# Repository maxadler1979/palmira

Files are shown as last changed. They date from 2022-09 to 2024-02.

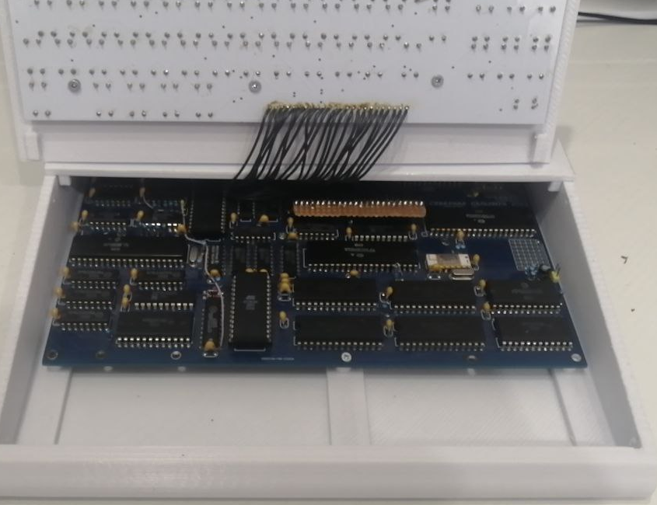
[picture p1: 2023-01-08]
пальмира_внутри.png

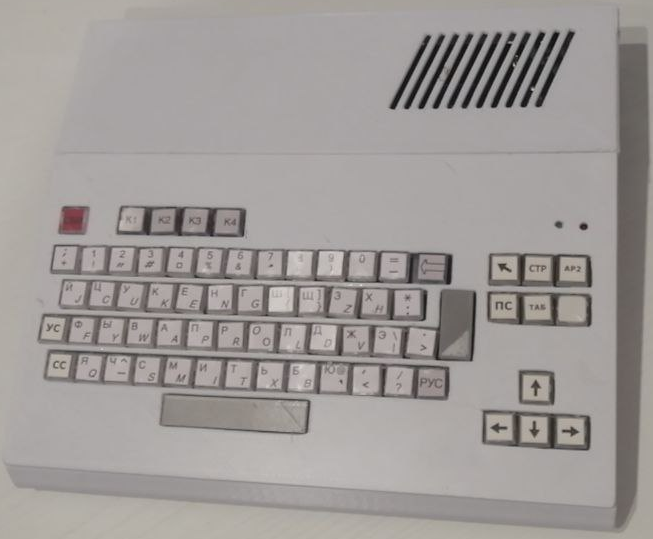
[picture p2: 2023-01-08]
пальмира.png

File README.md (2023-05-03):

# palmira
Улучшенная версия радиолюбительской ЭВМ Радио86 РК. Авторы доработок Ведущий специалист, Барсик, Виктор2313.
Центральный процессор остался КР580ВМ80А, может тактоваться частотой от стандартной 1,8 до 3х мегагерц (выборочные ревизии).
Видеочасть выполнена на БИС КР580ВГ75, имеет свой отдельный задающий генератор. Видеосигнал с цветом выводится на VGA монитор.
3х канальный звук выполнен на микросхеме таймера КР580ВИ53.
Внимание. прошивки ПЗУ устаревшие. Актуальные прошивки можно скачать из https://github.com/vpyk/palmira-stuff

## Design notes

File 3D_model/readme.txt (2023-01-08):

3D модели корпуса. Основная часть, клавиатура и верхняя крышка. Файлы открываются в Openscad.
Содержание файлов:
enter.stl - крышка для кнопки ввод
probel.stl - крышка для кнопок пробел
kb_palmira.stl - верхняя крышка для клавиатуры
verh_palm.stl - верхняя крышка корпуса
корпус_пальмира.stl - основной корпус

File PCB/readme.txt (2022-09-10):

i2c_radio - Файл печатной платы I2C расширения
radio_usb - Файл печатной платы отладчика USB
sd_radio - Файл печатной платы SD адаптера
rk86_52kRF_v2.3 - печатная плата Пальмира

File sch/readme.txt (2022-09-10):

ram_FONT_RK86 - Схема пальмиры
sd_radio - схема SD адаптера
i2c_radio - схема I2C адаптера
Схемы в формате PCAD2006

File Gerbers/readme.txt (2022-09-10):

В гербере клавиатуры допущена ошибка, поменяны местами кнопки влево и вправо. Так как исходник потерян выложено как есть.

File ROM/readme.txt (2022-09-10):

zg_rom8_ap - Файл для прошивки ПЗУ знакогенератора (со шрифтом псевдографики апогея)
mon_rom8 - Файл для прошивки ПЗУ монитора

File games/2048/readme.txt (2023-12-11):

Исходники и порт игры ДЛЯ РАДИО 86 РК.  Для компиляции запустить compile.bat, необходимо иметь на диске Z88DK.

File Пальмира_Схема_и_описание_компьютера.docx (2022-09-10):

Схема и описание компьютера.

Северная Пальмира является клоном компьютера Радио86-РК, обладает максимальной совместимостью при ряде принципиальных схемотехнических доработок. Примененные в схеме комплектующие состоят из распространенных логических микросхем и БИС комплекта серии 580 производства СССР –СНГ (кроме 2х статических ОЗУ 62256), легкодоступны и не имеют микросхем PROM или ПЛИС. Источник питания компьютера подразумевает использование внешнего преобразователя напряжений -5 и +12В. Для них предусмотрены макетные отверстия. Для подключения внешних устройств выведена системная шина и порты микросхемы кр580вв55. Разъем клавиатуры выведен стандартный и подразумевает подключение стандартной клавиатуры рк86.

Основные отличия от оригинальной версии Радио86РК:

1 – Размер шрифта 8х16 точек. Из за этого в прошивке оригинального монитора необходимо поменять настройки видеоконтроллера кр580вг75. (см. примечание 1)

2 – Поддержка атрибутов цвета и инверсии. Также в прошивке оригинального монитора необходимо поменять настройки видеоконтроллера кр580вг75. (см. примечание 1)

3 – Изменена частота видеоконтроллера, из за этого не могут поддерживаться нестандартные видеорежимы оригинала (основная проблема), например автору так и не удалось настроить режим , где количество символов в столбце может быть больше 23. Возможно данная проблема кроется в том, что размер символа вырос до 16 точек.

4 – Выход на бытовой телевизор переделан на выход VGA для подключения жк монитора. Для поддержки частот монитора соответственно пересчитаны частоты видеоконтроллера (см пункт3).

Тем не менее, появились достоинства, отличающие данный компьютер как по функционалу так и по техническим характеристикам, при сохранении полной совместимости с 90% старого ПО.

Основные нововведения:

1 – Область памяти может программно расширяться до 16 КБ по адресам 0x8000 – 0xBFFF. При этом порты переключаются на адреса памяти 0xC200 и 0xC400 соответственно.

2 – Добавлена дополнительная память 2КБ по адресам 0xD000-0xD7FF.

3 – Добавлен программно переключаемый банк памяти объемом 32КБ на стандартные адреса 0x0000-0x7FFF.

4 – Добавлен музыкальный синтезатор(трехканальный таймер), позволяющий использовать в программах 3 канальную полифонию. Адрес 0xCC00.

5 – Появились 3 дополнительных адреса выборки внешней периферии благодаря расширенному дешифратору. (адреса 0xC600,0xC800 и 0xCA00)

6 – ОЗУ в области 0xD800-0xDFFF может программно переключаться для использования вместо ПЗУ знакогенератора, благодаря чему возможно применение альтернативного шрифта с изменением в ходе выполнения программы. ОЗУ доступно как на чтение так и на запись. При применении в работе с ВГ75 ОЗУ для считывания и записи недоступно. Для изменения содержимого этого ОЗУ, достаточно переключить 1 бит в управляющем байте и записать этот байт в область памяти 0xCE00.

7 – ПЗУ знакогенератора расширена до 8 КБ, благодаря чему появилась возможность программно переключать еще 3 вида альтернативных знакогенераторов.

8 – ПЗУ монитора расширено до 8 КБ, находится в адресах 0xE000-0xFFFF.

9- Добавлен программный переключатель, находящийся по адресу 0xCE00. Благодаря нему можно переключать периферию контроллера (до 5 устройств) один бит триггера выведен на внешний порт и может использоваться альтернативно.

10 – Процессорная часть и дисплейная часть компьютера тактируется разными частотами, благодаря чему появилась возможность тактирования микропроцессора вплоть до 3 МГц. При этом тактовая частота ВИ53 остается неизменной, так как она тактируется от частоты видеоконтроллера.

11 – В видеоконтроллере использованы все атрибуты, благодаря чему появилась возможность использовать атрибуты цвета и инверсии. Цветовая схема приведена к стандартам Толкалина и Акименко.

12 – Изменен размер шрифта символа до 8х16 точек. Благодаря этому применяемая псевдографика и шрифты обрели более изящный вид. Также, благодаря применению ОЗУ в качестве знакогенератора теперь стало возможно применять в игровых программах более качественные графические спрайты (до 127 спрайтов на одном экране при цветовой палитре до 8 цветов на 1 спрайт).

Рассмотрим более подробно периферию и блоки компьютера:

Процессорная часть система его тактирования и модуль DMA остался стандартным и схемотехнически не менялся.

Порты ввода вывода и клавиатура также не изменились. Схема компаратора для магнитофона не внедрялась, так как компьютер не рассчитан на использование с магнитофоном. Отверстия портов магнитофона выведены под альтернативное подключение. Отдельно стоит отметить схемотехнику видеоконтроллера, модуля дешифратора, 3х канального таймера, переключателя знакогенератора и блока ОЗУ.

Таблица адресов распределения памяти

0000 – 7FFF | Основное ОЗУ
8000 - BFFF | Дополнительное ОЗУ
C000 – C200 | Регистры видеоконтроллера
C200 – C3FF | Порт клавиатуры
C400 – C5FF | Порт расширения
C600 – C7FF C800 – CBFF CA00 – CBFF | Резерв Резерв Резерв
CC00 – CDFF | Регистры таймера ВИ53
CE00 - CFFF | Байт расширения конфигурации
D000 – D7FF | Дополнительное ОЗУ
D800 – DFFF | ОЗУ знакогенератора
E000 | Регистры контроллера ПДП
E000 - FFFF | ПЗУ монитора

Таблица разрядов байта расширения конфигурации

7 | 6 | 4 | 3 | 2 | 1 | 0
1–ОЗУ 0000-BFFF 0–ОЗУ 0000-7FFF | Переключение ОЗУ 0xD800 – 0xDFFF в работу в видеоконтроллере 1 – ОЗУ в работе с видеоконтроллером, 0 – ОЗУ в памяти процессора | Резерв | Биты конфигурации знакогенератора (разбивает 8КБ ПЗУ на 4 разных ЗГ) | | | Переключение банков ОЗУ по 32КБ 0 – основной банк, 1 – дополнительный банк

Пример. Если записать байт 0х82 по адресу 0хCE00 то будет выбран знакогенератор графического режима апогей бк01. Вся графика этого компьютера будет доступна на этом компьютере.

Ниже на рисунке приведена распиновка системного разъема расширения.

Системный разъем содержит шину данных компьютера, свободные адреса дешифратора, сигналы чтения записи, 5 адресных линий. Также к разъему подведено питание компьютера 5В. Этого достаточно для подключения всевозможной периферии от внешних видеоадаптеров до плат расширения.

Для проверки системного разъема автор развел несколько плат расширения, это плата отладчика (по сути это USB-COM переходник, который может использоваться как ком порт компьютера) и плата I2C контроллера. Под плату USB отладчика в ПЗУ компьютера прошит отладчик, который вызывается директивой O. Со стороны ПК должно работать программа NO Ice.

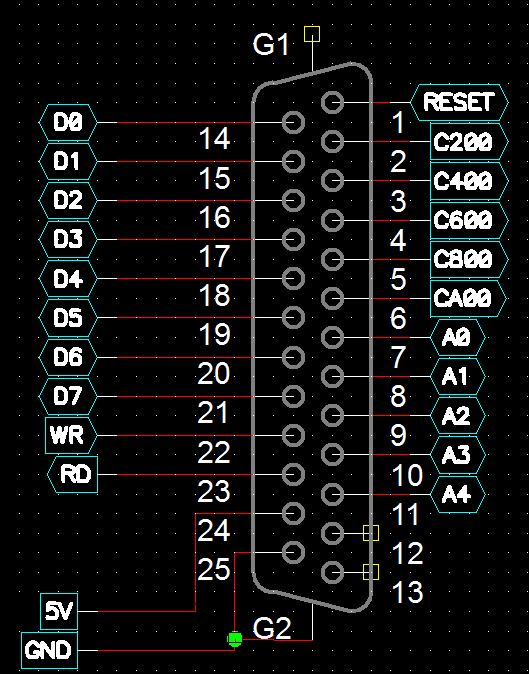
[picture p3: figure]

Дешифрирование микросхем ОЗУ по 2КБ осуществляет следующая схема.

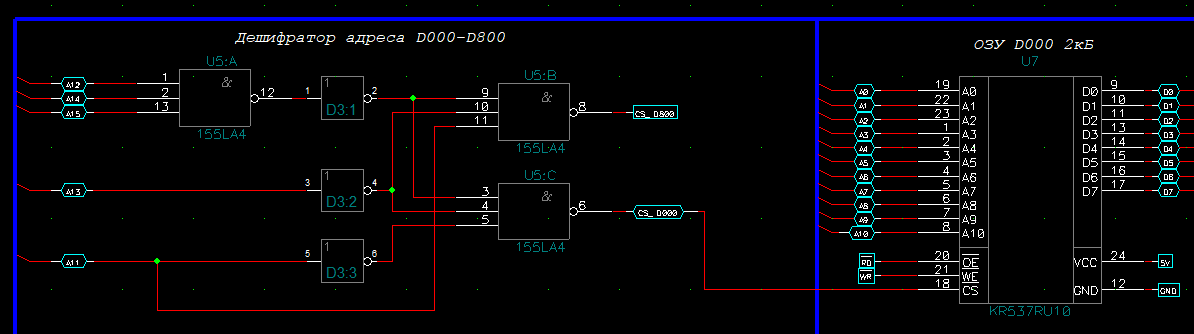
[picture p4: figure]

За переключение микросхемы ОЗУ в область памяти 0xd800-0xdfff отвечает следующие микросхемы. Для работы ОЗУ в шине процессора служит микросхема кр1533ап6, для переключения ее в работу с ВГ75 – кр1533ап5.

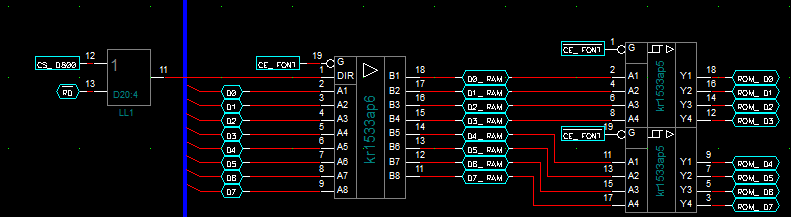
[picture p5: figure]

За переключение ОЗУ в работу с вг75 отвечают 4 микросхемы кр1533кп11.

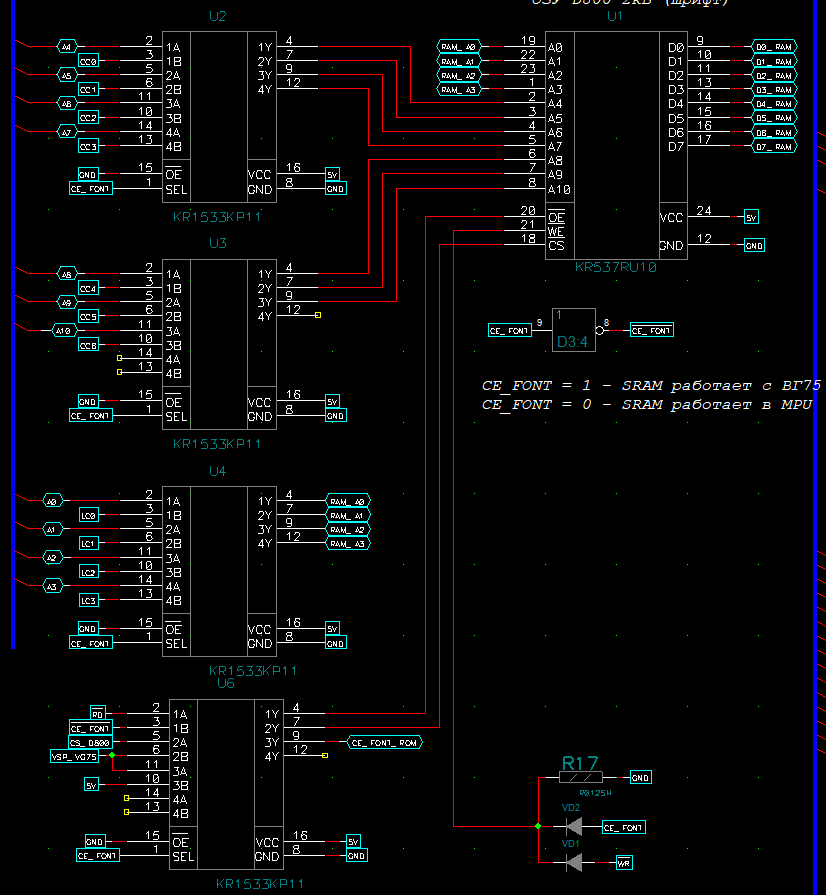
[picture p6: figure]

Программное переключение выполняет следующая схема.

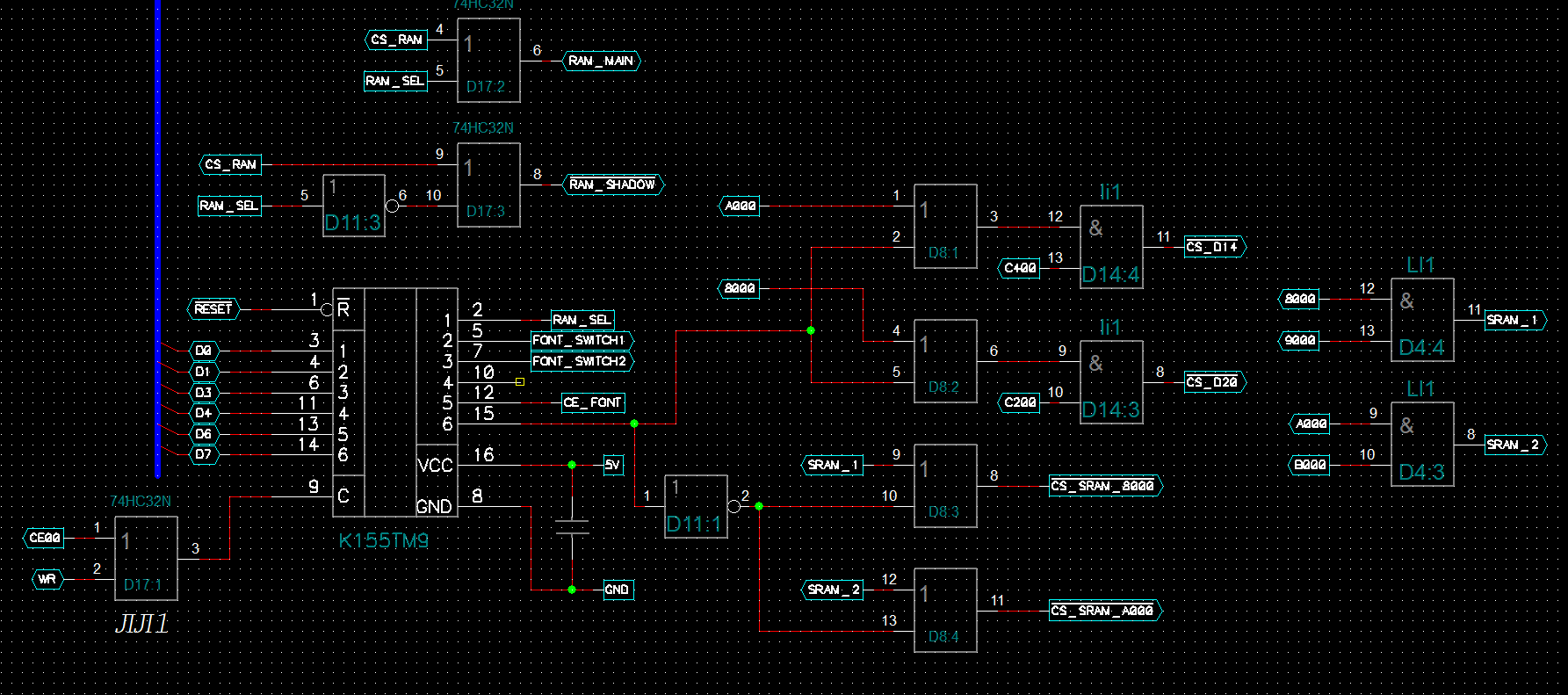
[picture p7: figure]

Для непрерывной выборки микросхем ОЗУ служат микросхемы D4.3 и D4.4. Для переноса портов В/В и клавиатуры служит логика из D8, D14, D11. При подачи из вывода 6 микросхемы к1533тм9 логического состояния, происходит переключение адресов выборки на ОЗУ вместо портов и наоборот.

Микросхемы ОЗУ по 8 КБ каждая имеют стандартное включение.

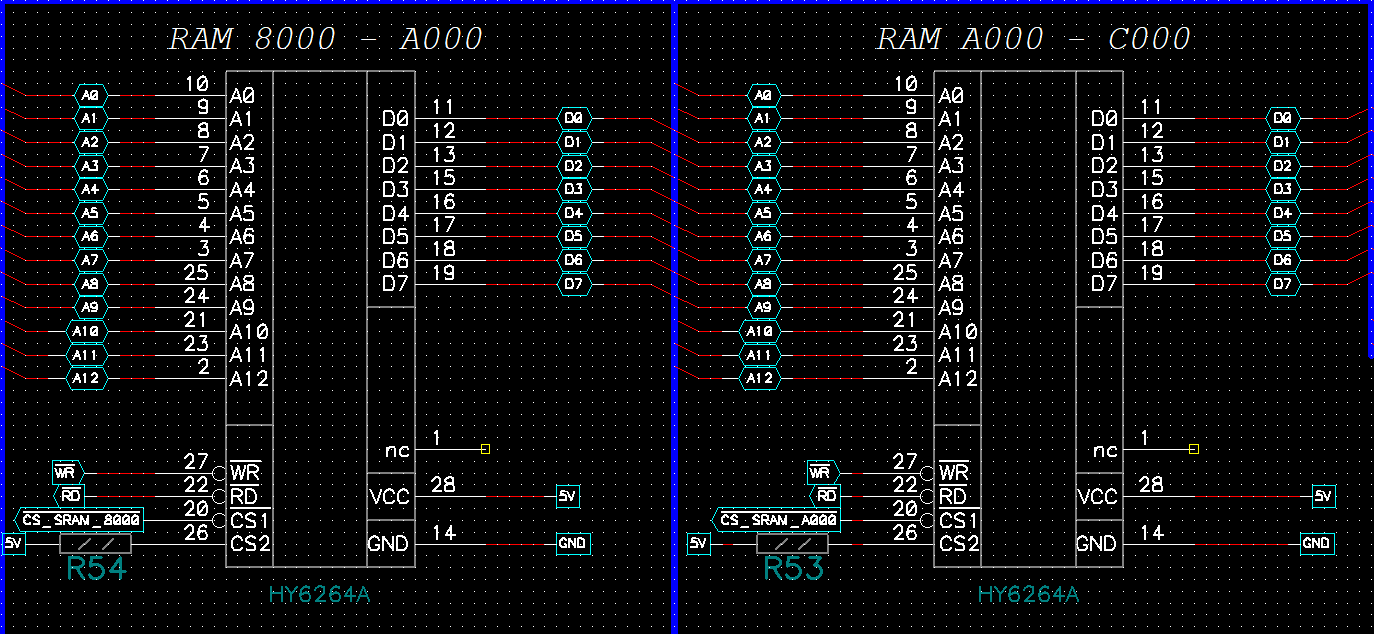
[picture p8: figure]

Для переключения банков ОЗУ по 32КБ предназначены микросхемы D17.2, D17.3 И D11.3

Основная и дополнительная RAM имеют стандартное включение

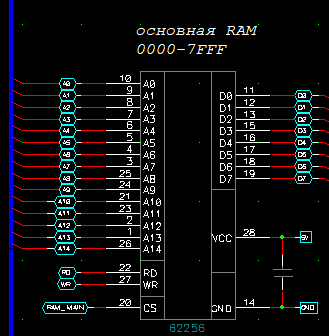
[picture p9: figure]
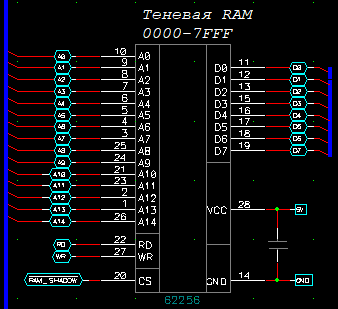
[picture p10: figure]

В качестве звуковой микросхемы используется 3х канальный таймер кр580ви53. Выходы микросхемы запараллелены резисторами номиналом 1кОм и через конденсатор выведен на контакт для подключения внешнего усилителя. Для усилителя на плате предусмотрены макетные отверстия.

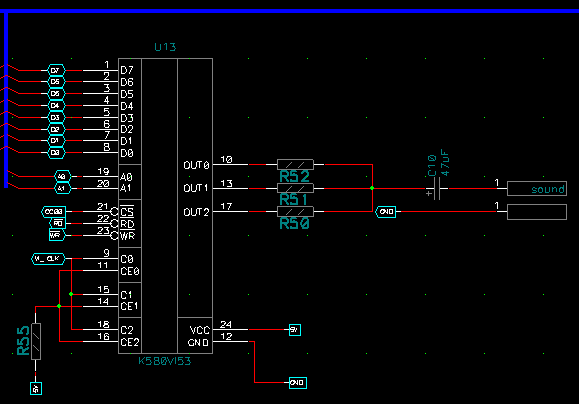
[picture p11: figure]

Для тактирования таймера используется микросхема кр1533ие5, тактовая частота для нее берется от генератора видеокарты

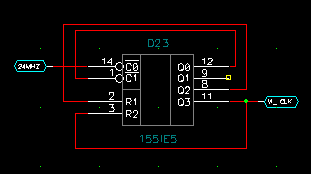
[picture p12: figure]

Дешифратор компьютера выполнен по стандартной схеме и состоит из 2 микросхем кр1533ид7. Схема сброса стандартная и не нуждается в пояснениях. Несколько слов о выборке ПЗУ монитора. Благодаря вентилям микросхемы D14 выборка осуществляется с адреса 0xE000. Выборка видеоконтроллера кр580вг75 висит на «родном» адресе 0xC000. DMA контроллер также подключен по стандартным в РК адресам 0xE000.

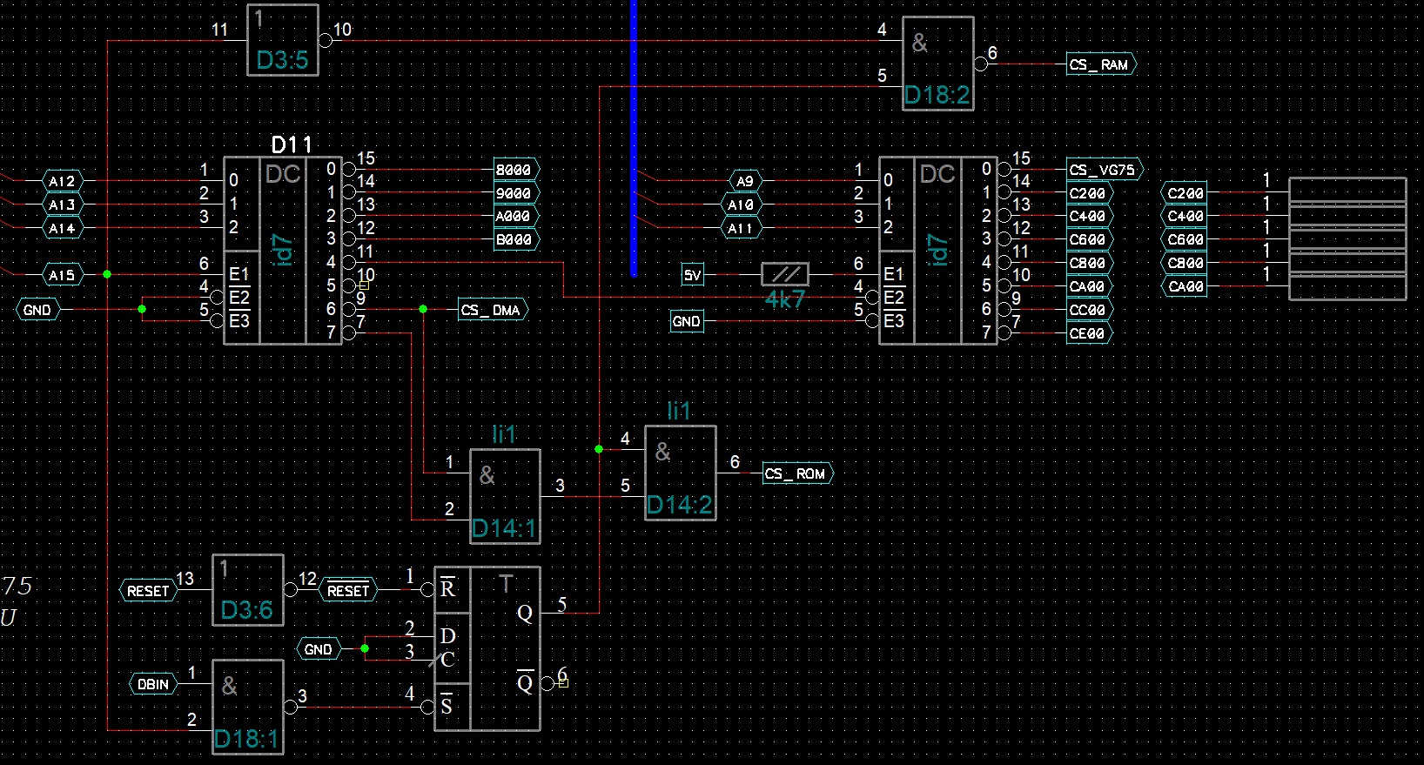
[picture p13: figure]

Процессор , его тактирование и контроллер DMA выполнен по стандартной схеме

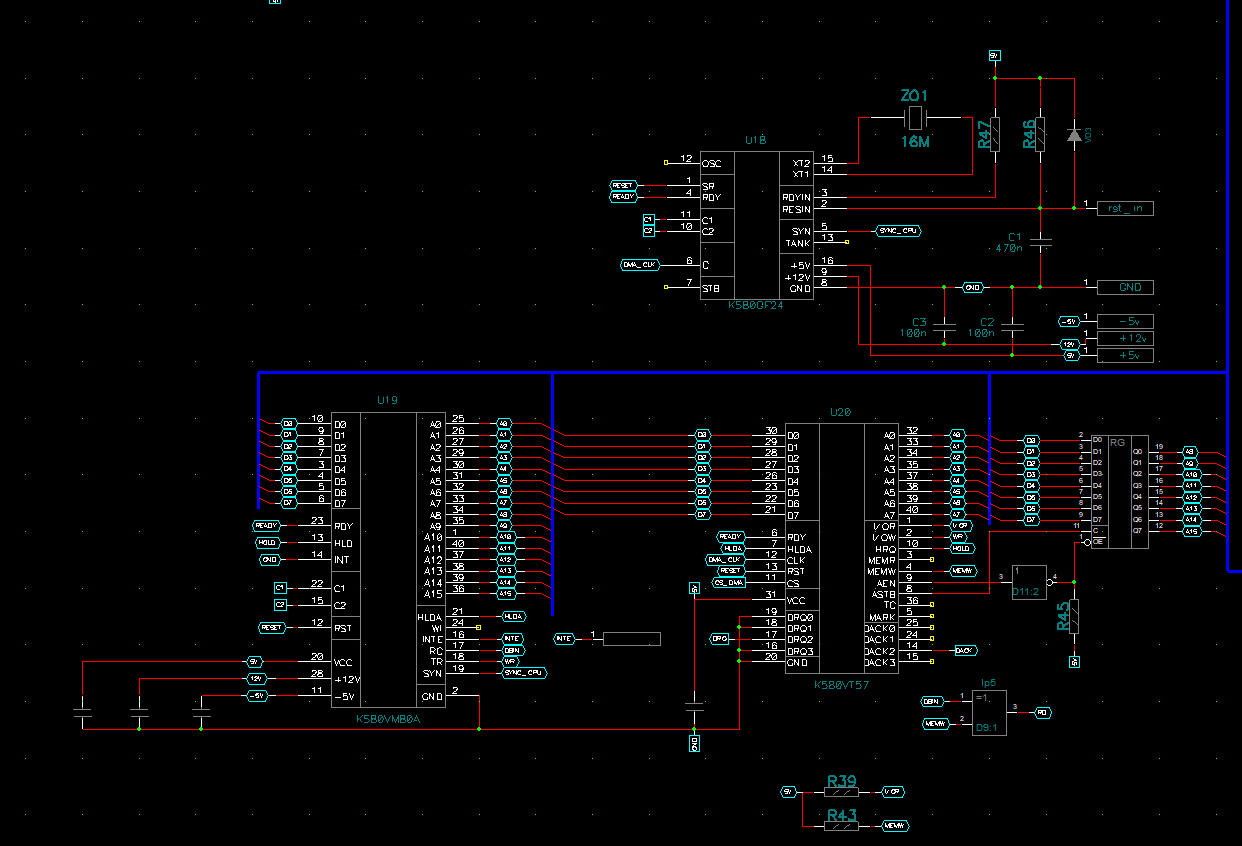
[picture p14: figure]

Порты ввода вывода и клавиатуры также выполнены по стандартной схеме РК

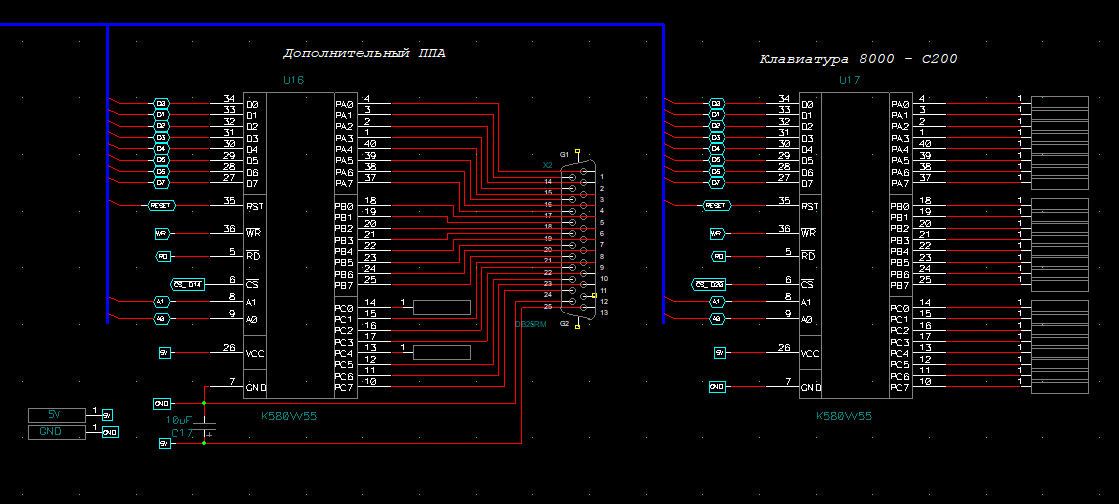
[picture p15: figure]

Разъем порта ВВ разведен на разъем DB25 который позволяет подключить периферию непосредственно к плате.

Для загрузки ПО в компьютер предусмотрен внешний дисковый контроллер, выполненный по схеме и проекту Алексея Морозова. По вызову директивой I монитора происходит считывание BIOS в память компьютера и далее загружается файловая оболочка. Пользователю остается только выбрать файл для загрузки. Проект и файлы можно найти в репозитории.

Схема видеоконтроллера:

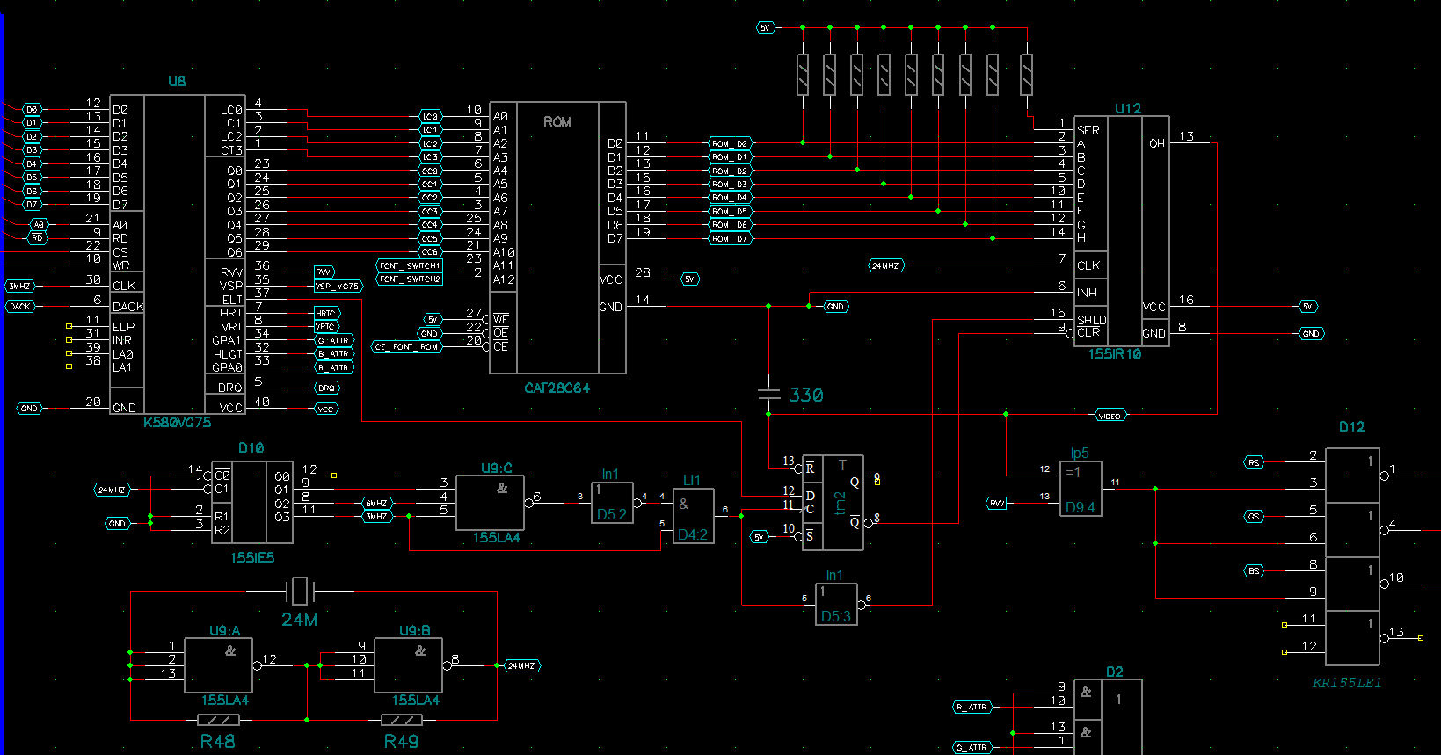
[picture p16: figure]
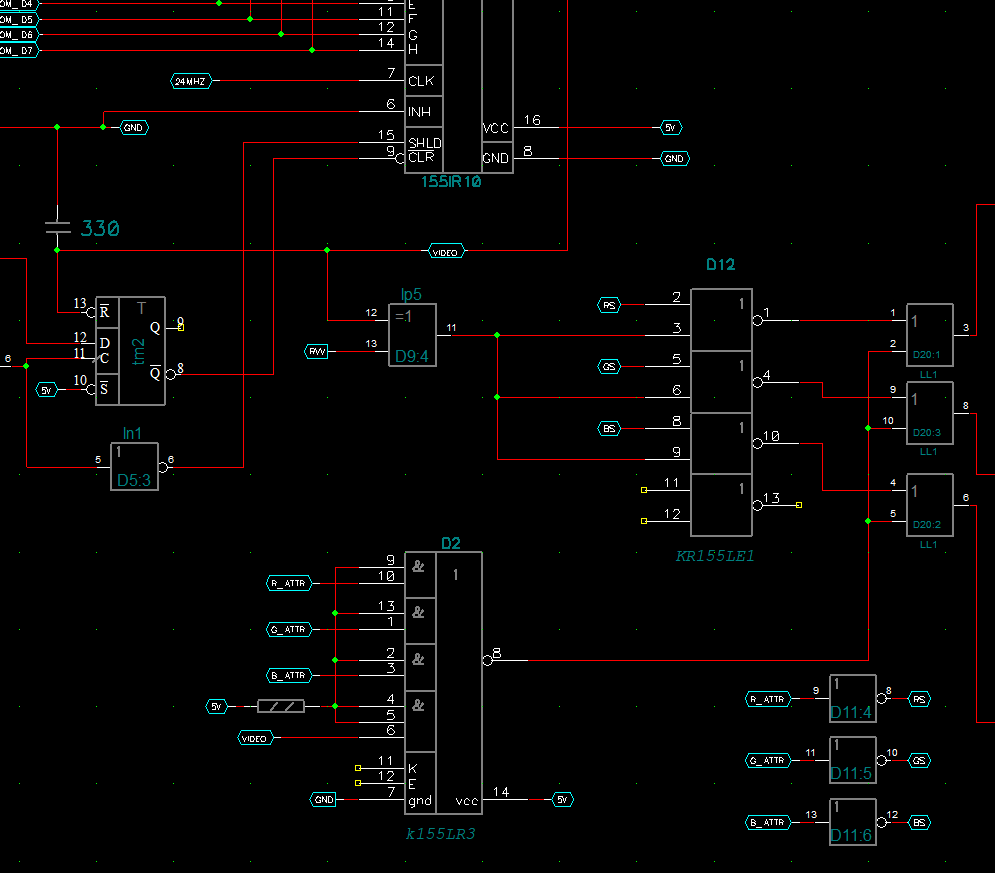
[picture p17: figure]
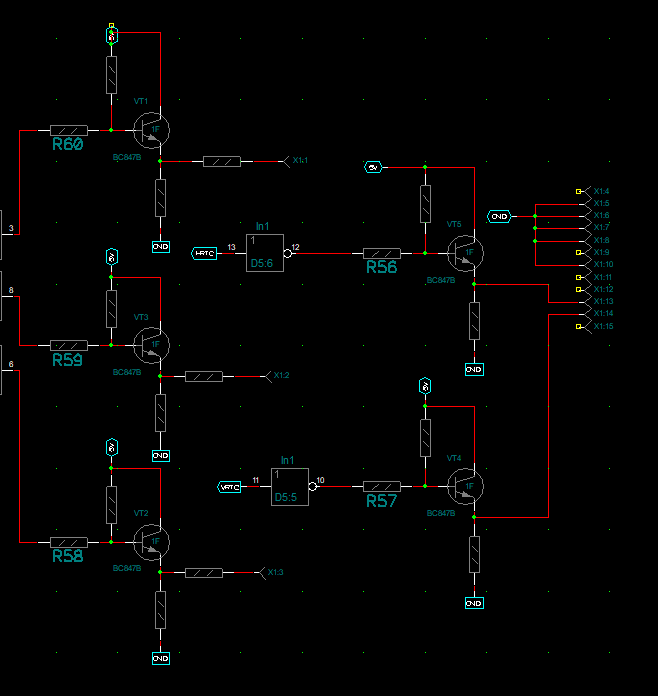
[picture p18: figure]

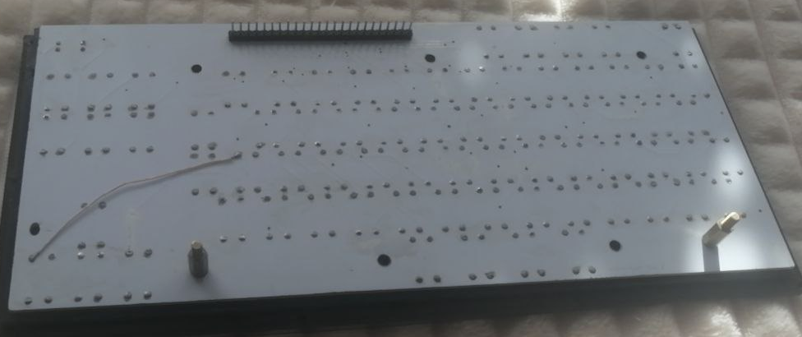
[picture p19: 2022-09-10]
foto/kb_bot.png

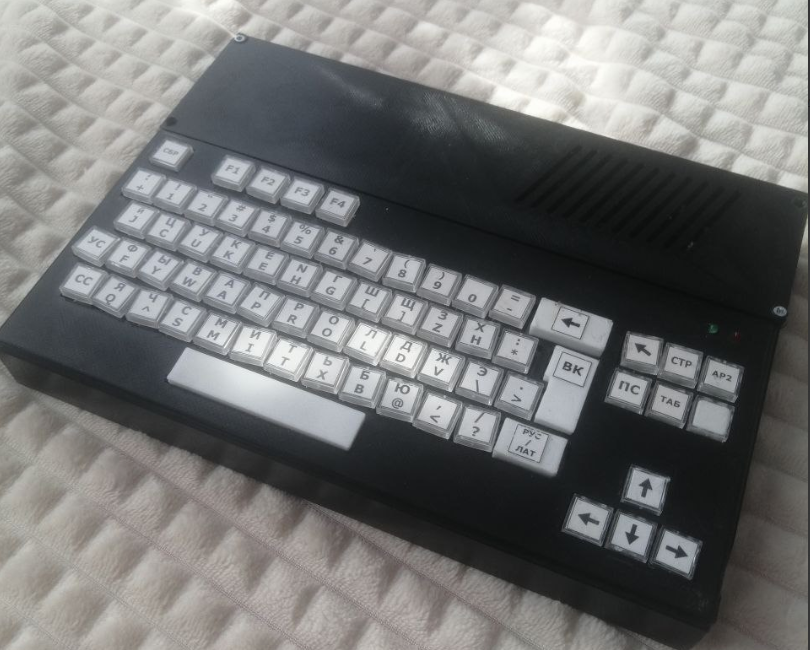
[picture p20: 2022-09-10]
foto/palm.png

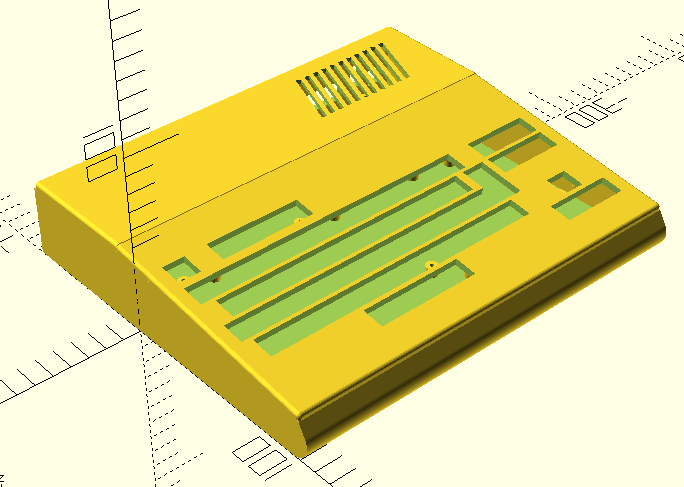
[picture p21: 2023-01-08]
3D_model/корпус.png

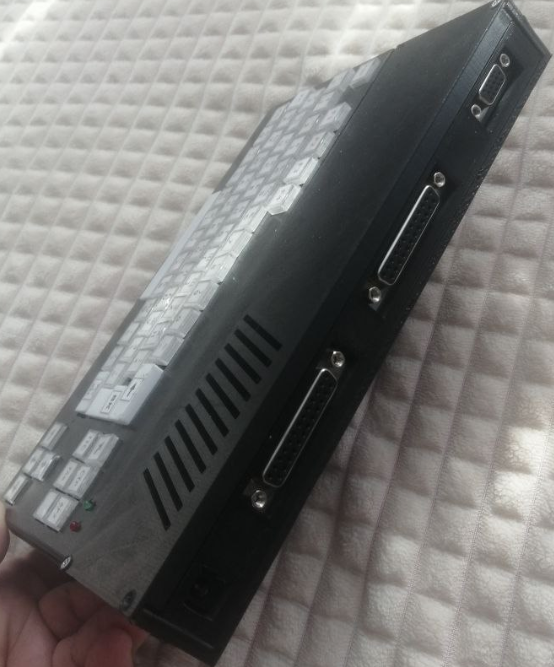
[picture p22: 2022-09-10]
foto/palm2.png

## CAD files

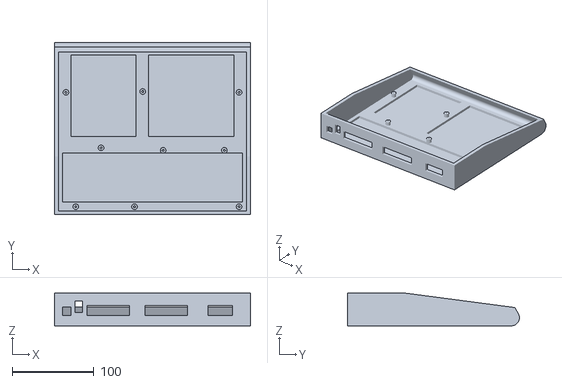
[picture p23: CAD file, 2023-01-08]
3D_model/корпус_пальмира.stl
240.0 x 210.5 x 40.0

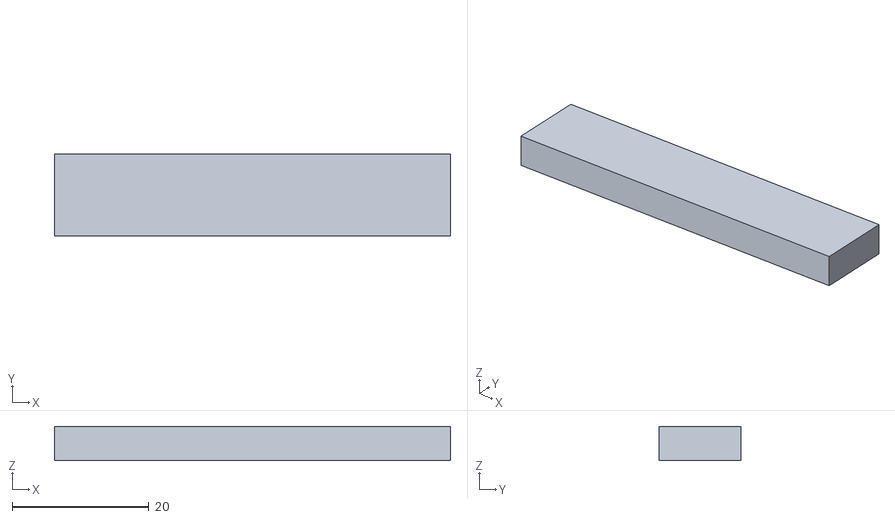
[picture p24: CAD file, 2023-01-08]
3D_model/probel.stl
58.0 x 12.0 x 5.00

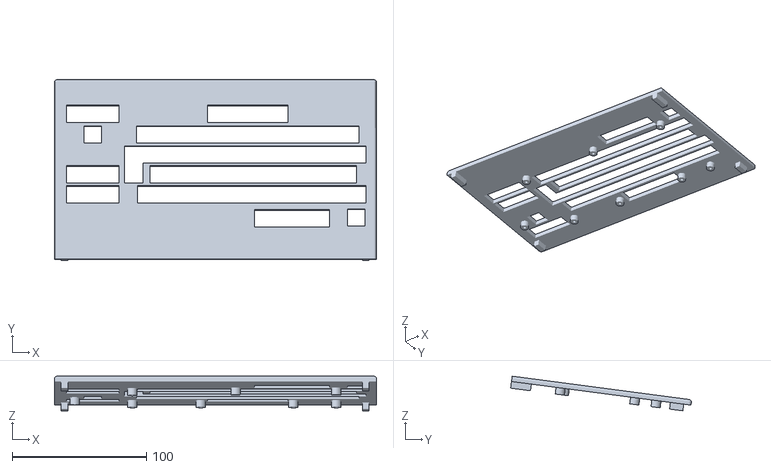
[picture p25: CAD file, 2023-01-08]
3D_model/kb_palmira.stl
240.0 x 134.8 x 25.8

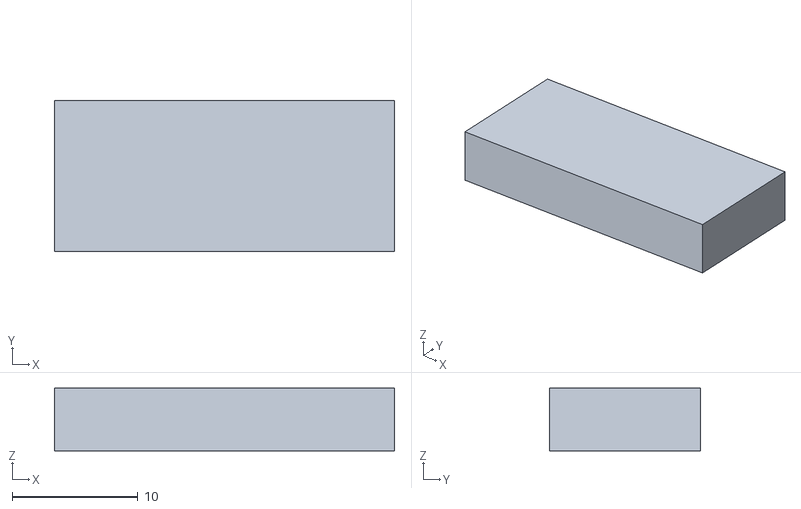
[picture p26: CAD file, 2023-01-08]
3D_model/enter.stl
27.0 x 12.0 x 5.00

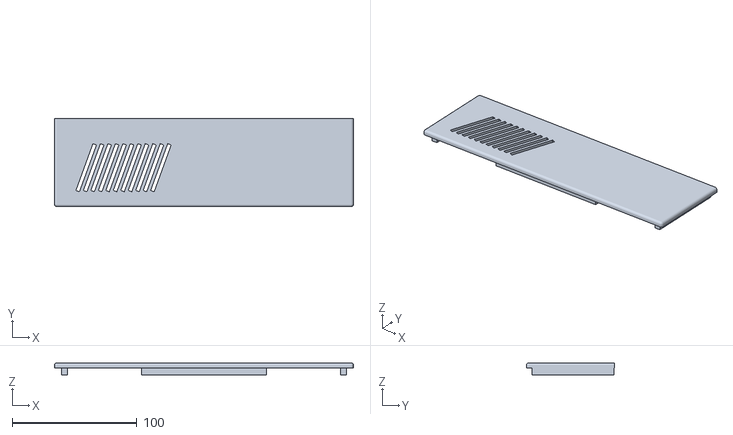
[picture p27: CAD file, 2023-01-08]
3D_model/verh_palm.stl
240.0 x 71.0 x 9.99

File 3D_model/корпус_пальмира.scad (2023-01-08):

module prizm_add_dfask(n, height, rib, r_fask, fn_fask, center = false)
{
  r = rib/sqrt(3);
  minkowski()
  {
    cylinder(height/2, r, r, $fn=n, center);
    cylinder(height/2, r_fask, r_fask, $fn=fn_fask*32, center);
  }
}

//базовая призма
module prizm_side(n, w, h, r, center = true)
{
  rotate([0,-90,180])
  {
    prizm_add_dfask(n, w, h, r,16, center);
  }
}
//призма - труба
module prizm_box(n, w, h, r, t, center = true)
{
  r2 = (r-t < 0) ? 0.1 :  r-t;
  rotate([0,-90,180]) difference()
  {
    prizm_add_dfask(n, w, h, r,16, center);
    translate([0,0,-0.5])prizm_add_dfask(n, w+3, h, r2,16, center);
  }
}








h=230;
r=10;
t= 5; // толщина корпуса
w=127;
z = h/(sqrt(3)*2) + r;
h2=40;
ts = 8; // толщина боковой стенки
ts2 = 5;


module stylus(h, r, fn_fask)
{
  difference()
  {
      union()
      {
        translate([0,0,h-r]) sphere(r,$fn=fn_fask*1);
        cylinder(h-r,r,r,$fn=fn_fask);
      }
      translate([-r,0,0]) cube([2*r, r, h]);
  }
}

module half_box_fask(w,l,h,r_fask,fn_fask)
{
  fn = fn_fask*4;
  translate([w/2,l/2,0]) hull()
  {
    translate([-w/2+r_fask,-l/2+r_fask,0]) stylus(h, r_fask, fn);
    translate([-w/2+r_fask,l/2,0]) stylus(h, r_fask, fn);
    translate([w/2-r_fask,-l/2+r_fask,0]) stylus(h, r_fask, fn);
    translate([w/2-r_fask,l/2,0]) stylus(h, r_fask, fn);
  }
}

module case_rk_top()
{
    difference() {
          
     half_box_fask(240,71,4,2,10);//cube([236,61,2],false);
     translate([10,10,-0.5])cube([96,55,2],false);
     translate([116,10,-0.5])cube([110,55,2],false);
     for (i=[140:6:200])
     translate([i-120,12,-0.5])rotate([00,00,70])cube([40,3,8],false);
    }


    translate([5.5,4.5,-6])   cube([5,66,6],false);
    translate([229.5,4.5,-6]) cube([5,66,6],false);
    translate([70,4.5,-6]) cube([100,4.5,6],false);
    //translate([10,0,-5]) cube([216,5,5],false);
    //translate([106,5,-5]) cube([10,45,5],false);
}

module stoyka_klav(x,y)
{
    translate([x,y,-5])
 difference() {
 cylinder($fn = 30, h = 6, r1 = 3.5, r2 = 3.5, center = false);
 cylinder($fn = 30, h = 6.5, r1 = 1.2, r2 = 1.2, center = false);   
    
}
}

module keyboard()
{
    difference() {
          
     half_box_fask(240,135,4,2,9);// cube([240,110,7],false);
     translate([2,20,0])
        {
             translate([172,41,-1.5]) cube([14,10,8],false); //пробел
        translate([64,-0.5,-1.5]) cube([60,13,8],false); //пробел
        translate([190,-0.5,-1.5]) cube([39,13,8],false);//стрелки влево вниз вправо
        translate([11,15,-1.5]) cube([166,13,8],false);  // нижний ряд
        translate([203,15,-1.5]) cube([13,13,8],false); //кнопка вверх
        translate([6,30,-1.5]) cube([180,13,8],false); //второй ряд снизу
        translate([13,45,-1.5])cube([154,13,8],false); // третий ряд снизу
        translate([172,45,-1.5])cube([14,13,8],false); //вк
        translate([190,45,-1.5])cube([39,13,8],false); //пс таб
        translate([6,60,-1.5])cube([170,13,8],false); // 4 ряд
        translate([190,60,-1.5])cube([39,13,8],false);
        translate([6.5,77.5,-1.5])cube([13,13,8],false); // сброс
        translate([33,78,-1.5])cube([56,13,8],false);
            
             
            
        }
            

    }
             stoyka_klav(30,26);
             stoyka_klav(62,26);
             stoyka_klav(131,26);
             stoyka_klav(182,26);
            
             stoyka_klav(30,98);
             stoyka_klav(105,98);
             stoyka_klav(182,95);
             stoyka_klav(225,42);
     translate([10.5,5.5,-5])rotate([0,0,90])cube([10,5,5],false);
     translate([10.5,120,-5])rotate([0,0,90])cube([15,5,5],false);
     translate([235,5.5,-5])rotate([0,0,90])cube([10,5,5],false);
     translate([235,120,-5])rotate([0,0,90])cube([15,5,5],false);
}





module stoyka(x,y)
{
    translate([x,y,-73])
 difference() {
 cylinder($fn = 30, h = 7, r1 = 3.5, r2 = 3.5, center = false);
 cylinder($fn = 30, h = 7.5, r1 = 1.2, r2 = 1.2, center = false);   
    
}
}



zw=240;
 module main_case()
intersection()
{
  //translate([0,50,h2/2])cube([169,h,h2],true); // уберем треугольник оставим санки # - подсветка  
      translate([0,0,h2/2])
  {
    hull()
    {  
      translate([0,-h/2+65,0]) cube([zw,71,h2],true); // уберем треугольник оставим санки # - подсветка   
     translate([0,h/2+20,-10])cube([zw,5,h2-20],true); //     
    }
  }
  translate([-00,0,z]) //rotate([0,0,0]) 
  union()
  {  
      difference() { 
       prizm_box(3, 240, h, r, t);
      
         
      /*    translate([-74,130,-65]) cube([159,6,5],false);   // фаска под клаву спереди 
       translate([-68,-87,-87.5]) cube([140,110,6],false); //дыра внизу 1
       translate([-68,37,-87.5])  cube([140,100,6],false);  //дыра внизу 2
       translate([-70,-87,-87.5]) cube([142,114,2.5],false); //фаска под дырку 1
       translate([-70,34,-87.5])  cube([142,104,2.5],false); //фаска под дырку 2
       //translate([-70,-80,-87.5]) cube([142,4,2.5],false); // фаска 
        translate([70,-83,-87.5]) cube([5,110,2.5],false); //фаска под дырку 1
          translate([70,34,-87.5]) cube([5,104,2.5],false); //фаска под дырку 1**/
      }
      difference() {
      translate([-120,0,0])prizm_side(3, ts2, h, r, 20); // боковая стенка
           // боковая стенка
     // translate([-64,-100,-52]) rotate([0,0,90]) cube([237,4,5],false);
     // translate([-63,-92,-87.5]) rotate([0,0,90])  cube([230,4,2.5],false);
     // translate([-64,18,-51.5])   rotate([0,6.8,90])  cube([126.7,4,5],false);//фаска на клаву на боковой стенке  
      }
      translate([115,0,0])prizm_side(3, ts2, h, r, 20); 
      
      // #stoyka(-94,-84);
      stoyka(-94,-76);
      stoyka(-22,-76);
      stoyka(106,-76);
      stoyka(-106,64);// -115х-81 правый левый угол -110х-81 правый верхний край платы
      stoyka(106,64);
      stoyka(-63,-4);
       stoyka(-12,65);
       stoyka(88,-7);
      stoyka(13,-7);
      difference() {
       translate([-120,-86,-86]) cube([240,5,50],false);// задняя стенка
       //-115 начало правой стенки
       translate([-100,-80,-53.5]) rotate([90,180,0])cube([10,10,6],false);// отверстие под питание
       translate([-28,-80,-51.5]) rotate([90,180,0])cube([52,12,6],false);// порт сдшки
       translate([43,-80,-51.5]) rotate([90,180,0])cube([52,12,6],false);// порт системный   
       translate([98,-80,-51.5]) rotate([90,180,0])cube([30,12,6],false);// порт системный  
       translate([-95,-80,-60]) rotate([90,0,0])cube([9,14,6.5],false);// выключатель 
      // translate([-70,-83,-52]) rotate([0,0,0]) cube([155,6,5],false); // фаска под крышку
      // translate([-70,-83,-87.5]) rotate([0,0,0]) cube([145,4,2.5],false); // фаска под крышку снизу
      // translate([-10,-78,-71]) rotate([90,0,00]) cube([56,12,6.5],false);
  //translate([-15,-85,-66]) rotate([90,0,00])#cylinder($fn = 0, h = 15, r1 = 1, r2 = 1, center = false);
  //translate([48,-85,-66]) rotate([90,0,00])#cylinder($fn = 0, h = 15, r1 = 1, r2 = 1, center = false);
       //
       //translate([-45,-78.5,-66]) rotate([90,180,0]) cylinder($fn = 0, h = 7, r1 = 8, r2 = 7.8, center = false); //питание  
      // translate([169/2,-78,-63]) rotate([90,180,0]) cube([9,14,3],false);// вставка для скрепления
      }
  }
  // translate([-0.5,5,34]) cube([237,6.5,6],false);
 }
 
module probel()
{
   
 difference() {
  cube([58,12,5],false);
  translate([1,1,-0.50])cube([56,10,4],false);  
}
}
 
 module enter()
{
   
 difference() {
  cube([27,12,5],false);
  translate([1,1,-0.50])cube([25,10,4],false);  
}
}
 

  translate([-120,0,0]) main_case();
  translate([-240,-85,40])case_rk_top();
  translate([-0,119.5,22]) rotate([7.5,0,180])keyboard();





//enter();

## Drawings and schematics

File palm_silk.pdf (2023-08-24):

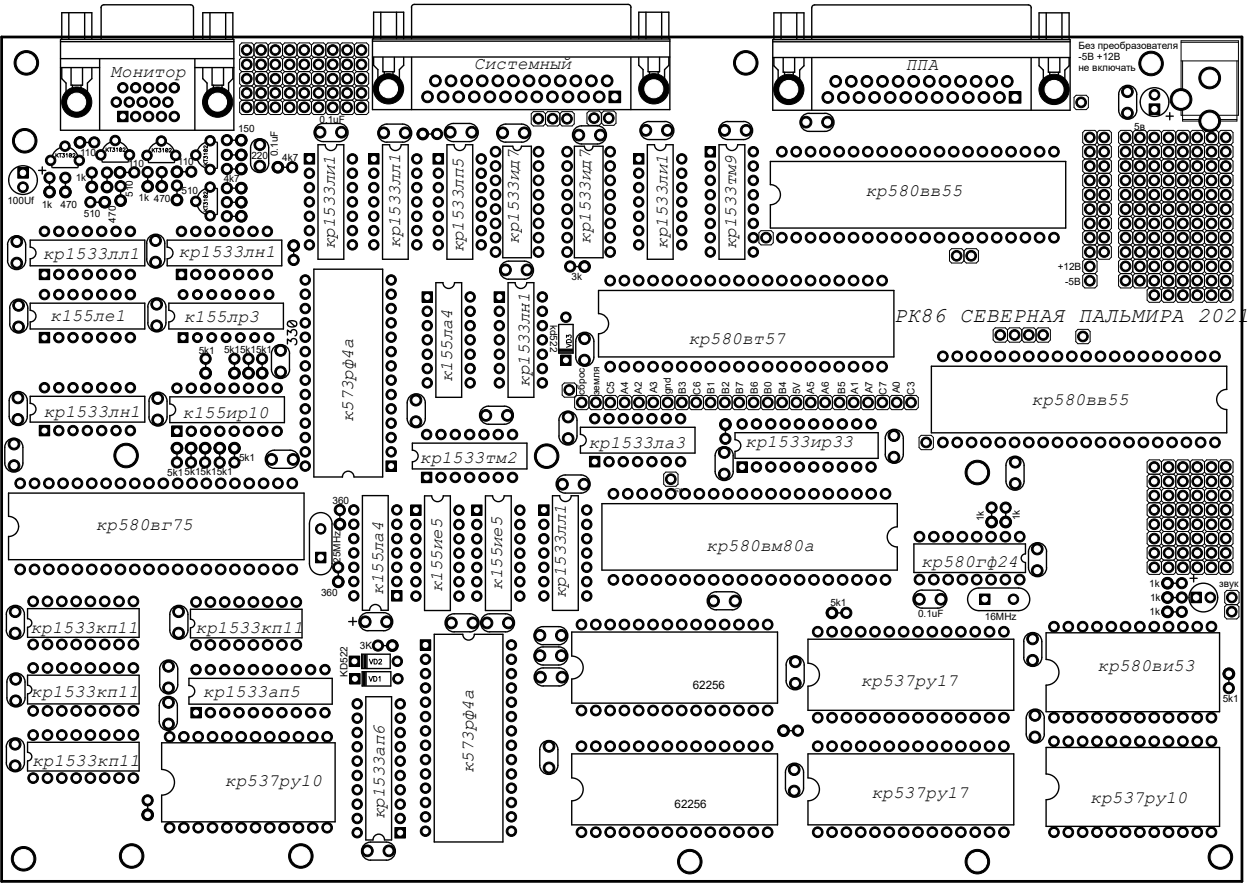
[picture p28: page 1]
Без преобразователя -5В +12В не включать; РК86 СЕВЕРНАЯ ПАЛЬМИРА 2021; земля C⁵; A²A³; B²B⁷; B⁰B⁴; A⁵A⁶; A¹A⁷; звук; 360 ²⁵MHz; 16MHz ¹k; KD⁵²²; кр580вв55 кр1533тм⁹; ППА; Монитор; Системный

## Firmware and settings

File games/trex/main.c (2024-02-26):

#include <string.h>
#include <stdint.h>
#include "main.h"
#include "splash.h"

extern void DrawString(const char* str, uint8_t x, uint8_t y);

uint8_t* VG75 = (uchar*)0xC000;
uint8_t* VT57 = (uchar*)0xE000;
uint8_t* vv55 = (uint8_t*)0xc200;
uint8_t* radio86rkVideoMem = (uchar*)(SCREEN + 78*3 + 8);
uint8_t  radio86rkVideoBpl = 78;
unsigned char coordata[2];
extern uint8_t* put_sprite_3;
extern unsigned  char dino3[];
extern unsigned  char dino2[];
extern unsigned  char dino1[];
extern unsigned char ground1[];
extern unsigned char ground2[];
extern unsigned char ground3[];
uint8_t end;
uint16_t score=0; 
extern char i_a;
extern char i_b;
extern char i_c;
extern char i_d;

unsigned char best_bmp[26] = {3,8,
	 0x13, 0x10, 0x13, 0x01, 0x12, 0x01, 0x07, 0x01,
         0x13, 0x10, 0x13, 0x01, 0x02, 0x10, 0x06, 0x00, 
	 0x03, 0x00, 0x03, 0x01, 0x03, 0x00, 0x02, 0x00
};
unsigned char score_bmp[38] = {3,12,
	0x04, 0x03, 0x04, 0x03, 0x10, 0x12, 0x05, 0x06, 0x03, 0x10, 0x13, 0x01,
        0x00, 0x05, 0x06, 0x00, 0x10, 0x11, 0x06, 0x06, 0x14, 0x01, 0x13, 0x01,
        0x02, 0x01, 0x00, 0x03, 0x00, 0x02, 0x01, 0x02,	0x00, 0x01, 0x03, 0x01
};
unsigned char game_over[202] = {
4,50,	
	
	
	0x17, 0x17, 0x03, 0x03, 0x17, 0x17, 0x17, 0x17, 0x03, 0x07, 0x17, 0x17, 0x17, 0x13, 0x17, 0x13, 
	0x17, 0x17, 0x17, 0x13, 0x03, 0x03, 0x17, 0x17, 0x17, 0x17, 0x17, 0x17, 0x17, 0x03, 0x07, 0x17, 
	0x17, 0x17, 0x13, 0x17, 0x13, 0x17, 0x17, 0x17, 0x13, 0x03, 0x03, 0x17, 0x17, 0x17, 0x13, 0x03, 
	0x07, 0x17, 0x17, 0x11, 0x17, 0x03, 0x17, 0x17, 0x17, 0x11, 0x17, 0x11, 0x17, 0x17, 0x17, 0x11, 
	0x02, 0x00, 0x17, 0x17, 0x17, 0x11, 0x03, 0x07, 0x17, 0x17, 0x17, 0x17, 0x17, 0x17, 0x11, 0x17, 
	0x11, 0x17, 0x17, 0x17, 0x11, 0x07, 0x01, 0x17, 0x17, 0x17, 0x11, 0x03, 0x07, 0x17, 0x17, 0x17, 
	0x11, 0x17, 0x01, 0x17, 0x17, 0x15, 0x03, 0x01, 0x17, 0x17, 0x17, 0x11, 0x14, 0x10, 0x17, 0x17, 
	0x17, 0x11, 0x15, 0x11, 0x17, 0x17, 0x17, 0x11, 0x03, 0x03, 0x17, 0x17, 0x17, 0x17, 0x17, 0x17, 
	0x15, 0x03, 0x05, 0x17, 0x17, 0x17, 0x17, 0x10, 0x16, 0x17, 0x17, 0x17, 0x11, 0x03, 0x03, 0x17, 
	0x17, 0x17, 0x11, 0x14, 0x02, 0x17, 0x17, 0x17, 0x17, 0x17, 0x17, 0x17, 0x17, 0x17, 0x17, 0x17, 
	0x17, 0x17, 0x17, 0x17, 0x17, 0x17, 0x17, 0x17, 0x17, 0x17, 0x17, 0x17, 0x17, 0x17, 0x17, 0x17, 
	0x17, 0x17, 0x17, 0x17, 0x17, 0x17, 0x17, 0x17, 0x17, 0x17, 0x17, 0x17, 0x17, 0x17, 0x17, 0x17, 
	0x17, 0x17, 0x17, 0x17, 0x17, 0x17, 0x17, 0x17

};
void waitVSync() {
 #asm
    lxi h,0c001h
    mov a,m
waitVSync_1:
    mov a, m
    ani 20h
    jz waitVSync_1
  #endasm
}








void screen_setup(uint video_mem,uint length)
{
  VG75[1] = 0; //
  VG75[0] = 0x4d; //
  VG75[0] = 0x22; //
  VG75[0] = 0x1e; //7e
  VG75[0] = 0x53; //
  VG75[1] = 0x23; //
  waitVSync();
  VT57[8] = 0x80; //
  VT57[4] = (uchar)(video_mem); //
  VT57[4] = (uchar)((video_mem)>>8); //
  VT57[5] = (uchar)((length)-1); //
  VT57[5] = 0x40 | (uchar)(((length)-1)>>8); //
  VT57[8] = 0xA4; //	
}

uint8_t key_scan(uint8_t row) // возвращает код нажатой клавиши
{
	uchar z = 0;
	vv55[0] = row;
	return vv55[1];
}

 uint8_t GetInput()
{
  uint8_t kb;
  kb=0xff;

//dig=key_scan(0xfb);//fb - 1(253)2(251)3(247)4(239)5(223)6(191)7(127)
 kb=key_scan(0x7e); //7e = f1 f2 f3 f4 f5 space y z x
   if (kb==127) //space
    {
        return KEY_space;
    }

 kb=key_scan(0xfd);
   if (kb==251)
    {
       return KEY_enter;
    }

   if (kb==223)
    {
      
        return KEY_up;
    }
   if (kb==127)
    {
       return KEY_down;
    }
   if (kb==239)
    {
      return KEY_left;
    }
   if (kb==191)
    {
        return KEY_right;
    }
return kb;

}


uint16_t GetRandFromSeed(uint16_t randVal)
{
	uint16_t lsb = randVal & 1;
	randVal >>= 1;
	if (lsb == 1) randVal ^= 0xB400u;
    	return randVal;
}

uint16_t GetRand()
{
	static uint16_t randVal = 0xABC;

	randVal = GetRandFromSeed(randVal);
  
   return randVal;
}

int random(int min, int max)
{
     if(min >= max) {
        return min;
    }
    return min + GetRand() % (max - min);
}







void about(void)
{
clrscr();
create_table();
put_sprite_3 = about_scr;//
put_sprite(8,4);
DrawString("This game was written by  ", 21, 30);
DrawString("Pashkevich M A in 2024 SPB", 21, 36);
DrawString("in Z88DK C for RADIO 86RK ", 21, 42);
DrawString("Beta Version              ", 21, 48);
while(key_scan(0xfd)!=251);
}


void main() {
int n;
char s;

uint16_t best_score = 0; 
clrscr();
screen_setup(SCREEN,2730);
create_table();

put_sprite_3 = zastavka;//
put_sprite(8,4);

while(key_scan(0xfd)!=251)
{
if (key_scan(0x7e)==127)
    {
     about();
     break;
    }

}
clrscr();
create_table();



i_a=0;i_b=0;i_c=0;i_d=1;      
start_game:
score = (i_a*1000)+(i_b*100)+(i_c*10)+i_d-1;
i_a=0;i_b=0;i_c=0;i_d=0;
if (best_score<score) best_score = score;
dino_init();
cactus_init();
ptero_init();
score = 0;
put_sprite_3 = best_bmp;//
put_sprite(7,3);
DrawUInt(best_score, 23, 3); 
put_sprite_3 = score_bmp;//
put_sprite(52,3);

  while(1) 
  {
check_player();
cactus_check();
ptero_check();



waitVSync();
scroll();

cactus_core();
dino_core();
ptero_core();
DrawScore(66, 3); 
inc_score(); 
if (end==1) break;
  }

put_sprite_3 = game_over;//
put_sprite(16,6);

while(key_scan(0xfd)!=251);
clrscr();
create_table();
end =0;
goto start_game;
}

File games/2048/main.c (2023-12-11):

#include <string.h>
#include <stdint.h>
#include "main.h"
#include "rnd.h"
#include "anime.h"
#include "panel.h"
#include "score.h"
#include "sprite.h"

unsigned char kb=0;


ST_GAME Game;

extern uint8_t xs;
extern uint8_t ys;
extern uint8_t ws;
extern uint8_t hs;
extern uchar* radio86rkVideoMem;
void draw_main_screen(void)
{
        lcdPrintText("TINY", 0, 0);//OledDrawStr( 0, 0, "TINY");
	    lcdPrintText("2048", 0, 8);//OledDrawStr( 0, 1, "2048");
        lcdPrintText("SCORE", 97, 0);//OledDrawStr(16, 0, "SCORE");
	//lcdPrintText("Портировал", 18, 16); //OledDrawStr(17, 2, "BEST");  
}

void GameExecReset(void)
{
	AnimeInit();
	PanelInit();
	ScoreInit();
	SpriteInit();
	PanelMakeCell();
	PanelMakeCell();
	GameSetAct(GAME_EXEC_ANIME);
}
//---------------------------------------------------------------------------
void GameExecAnime(void)
{
	//PanelDraw();
	//ScoreDraw();

	SpriteDraw();
	AnimeExec();
	if(AnimeIsEnd() == FALSE)
	{
		return;
	}
        
	if(ScoreIs10() == TRUE || PanelIsGameOver() == TRUE)
	{
		GameSetAct(GAME_EXEC_OVER);
	}
	else
	{
		GameSetAct(GAME_EXEC_PLAY);
	}
}


void panel_clear(void)
{
    #asm
    
    
            LXI  H,0
            DAD  SP
            SHLD  spsave
            ;сохранили стек

        mvi c,16;//
        lxi h, 06b02h; 
        mov e, m
        inx h
        mov d, m
         lhld _radio86rkVideoMem; (загрузим адрес куда выводить графику)
        dad d
        xchg
        mov l,c; загрузим координату х в HL
        mvi h, 0
        dad d ;прибавим к DE
        ; выше мы вычислили адрес памяти экранной области с учетом координат (в DE хранится адрес экрана со смещением по координатам)
            mvi a,32; 
            lxi d, 79
            cma
            add e
            mov e, a
			mvi b,30; // очистим 30 строк
 
start_draw:

 mvi a,4; // 4 раза по 8 (очистим 32 символа по х)
viv:
  
  MVI  M,0 ;1
  INX  H
  MVI  M,0 ;2
  INX  H
  MVI  M,0 ;3
  INX  H
  MVI  M,0 ;4
  INX  H
  MVI  M,0 ;5
  INX  H
  MVI  M,0 ;6
  INX  H
  MVI  M,0 ;7
  INX  H
  MVI  M,0 ;8
  INX  H
  dcr a;
  jnz viv;
  DAD  D;     следующая строка очищаемой области
 
  dcr b
  jnz start_draw
 
  ;далее восстановим стек и выход
  LHLD  spsave
  SPHL
  RET
spsave:
  defw  1
qq:
    defb 0
    defb 0
#endasm
}




//---------------------------------------------------------------------------
void GameExecPlay(void)
{
	//PanelDraw();
	ScoreDraw();
  
	SpriteDraw();

	

	if(GetInput()==KEY_up) //нажали кнопку вверх
	{
               
		PanelMoveUp(); //передвинем панель вверх
                
		GameSetAct(GAME_EXEC_JUDGE);
	}
	else if(GetInput()==KEY_right)
	{
                
		PanelMoveRight();
                //panel_clear();
		GameSetAct(GAME_EXEC_JUDGE);
	}
	else if(GetInput()==KEY_down)
	{
                
		PanelMoveDown();
//panel_clear();
		GameSetAct(GAME_EXEC_JUDGE);
	}
	else if(GetInput()==KEY_left)
	{
               // panel_clear();
		PanelMoveLeft();
                
		GameSetAct(GAME_EXEC_JUDGE);
                //panel_clear();
	}

	if(GetInput()==KEY_enter)
	{
        clear_screen();
        draw_main_screen();     
		ScoreSaveBest();
		GameSetAct(GAME_EXEC_RESET);
	}
}
//---------------------------------------------------------------------------
void GameExecJudge(void)
{
	//PanelDraw();
	//ScoreDraw();
	SpriteDraw();


	if(AnimeIsDispOnly() == FALSE)
	{
		PanelMakeCell();
	}

	GameSetAct(GAME_EXEC_ANIME);
}
//---------------------------------------------------------------------------
void GameExecOver(void)
{
	panel_clear();
	ScoreDraw();
	SpriteDraw();


	lcdPrintText("GAME", 0, 7);//OledDrawStr(0, 6, "GAME");

	if(ScoreIs10() == TRUE)
	{
		lcdPrintText("CLR", 0, 15);//OledDrawStr(0, 7, "CLEAR");
	}
	else
	{
		lcdPrintText("OVER", 0, 15);//OledDrawStr(0, 7, "OVER");
	}

	if(GetInput()==KEY_enter)
	{
                clear_screen();
                draw_main_screen();
		ScoreSaveBest();
		GameSetAct(GAME_EXEC_RESET);
	}
}
//---------------------------------------------------------------------------
void GameSetAct(u8 act)
{
	Game.act = act;
}








void GameLoop(void)
{
	switch(Game.act)
	{
		case GAME_EXEC_RESET: GameExecReset(); break;
		case GAME_EXEC_ANIME: GameExecAnime(); break;
		case GAME_EXEC_PLAY:  GameExecPlay();  break;
		case GAME_EXEC_JUDGE: GameExecJudge(); break;
		case GAME_EXEC_OVER:  GameExecOver();  break;

		default:
			break;
	}

//	OledDrawStr(0, 4, "%03d %x", FrameGetCpuPercentMax(), FrameGetCnt());
}


void main() {

int s;
    
clear_screen();
screen_setup(SCREEN,2730);
create_tbl();
RndInit();
_memset(&Game, 0x00, sizeof(ST_GAME));

            lcdPrintText("TINY", 40, 0);//OledDrawStr( 0, 0, "TINY");
	    lcdPrintText("2048", 40, 8);//OledDrawStr( 0, 1, "2048");
            lcdPrintText("Автор Akkera", 9, 16);//OledDrawStr( 0, 1, "2048");
            lcdPrintText("Портировал", 18, 24); //OledDrawStr(17, 2, "BEST");  
            lcdPrintText("Ведущий", 26, 32); //OledDrawStr(17, 2, "BEST");  
            lcdPrintText("Специалист", 18, 40); //OledDrawStr(17, 2, "BEST");  
            lcdPrintText("Начало - ввод", 7, 48);
while(GetInput()!=KEY_enter);
	
         clear_screen();
         draw_main_screen();
  while(1) 
  {
   GameLoop();
   
  // DrawInt(Rnd32(),50, 50);
   //s++;
 
  }
}

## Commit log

2023-01-08 Add files via upload
    Исправленная весия клавиатуры
2023-08-24 Добавил расположение элементов и номиналы
2023-08-24 Исправлена шелкография
2023-08-24 Новые герберы с исправленной шелкографией
2024-03-20 Версия игры под обычный радио86 рк
2024-04-24 Исходники игры trex под радио86 рк
2024-04-24 Исходники игры trex для радио86 рк
2025-01-27 Исходник демы
